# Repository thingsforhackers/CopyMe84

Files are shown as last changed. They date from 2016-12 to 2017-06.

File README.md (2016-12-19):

# CopyMe84

## Introduction

This repo contains the source code and KiCad project files for our CopyMe84 game kit.

The CopyMe84 game plays very similar to the classic "Simon Says" electionic game.

A complete kit looks like this:

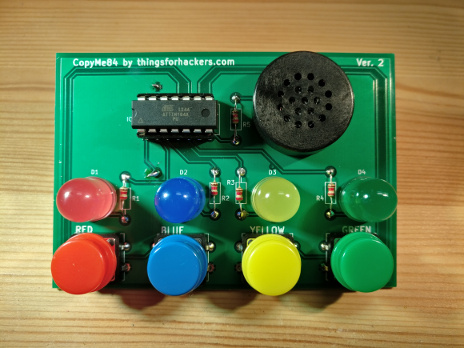
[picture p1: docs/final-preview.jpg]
Copy84A


Please visit [our store](https://thingsforhackers.com/store/) to purchase this kit.

When 1st powered on, i.e. when you insert the battery, it will play a nice('ish) title tune. After one loop of this tune, the game will enter power saving mode, press any button to wake it up.

To start the game, press any button during the title tune. The game play consitst of remember the sequence of LEDs, and pressing the corrosponding buttons in the correct order to repeat the sequence. Each sucessful loop the game will add another step to the sequence. To help, each LED flash is accompanied by a different beeper tone.

## HW Build Instructions

Full HW build instructions can be found on our [blog](https://thingsforhackers.com/post/build-instructions-copyme-84a/).

## SW Build Instructions

The kit contains a pre-programmed Ateml ATtiny84A microcontroller. However, as this is an open souce product you are albe to, infact we strongly encourge you to, modify, build and try out the code for yourself.

Inorder to build the code, you'll need a compiler that can target the Ateml AVR range of products. I would suggest starting [here](http://www.nongnu.org/avr-libc/user-manual/index.html).

If you're lucky enough to be on some sort of Linux box, I've written up [full instructions](https://thingsforhackers.com/post/installing-avr-libc/) on how to install the gcc tool chain for the AVRs.

Assuming you've got the gcc toolchain installed, the following shows you how to build the code:

If you haven't already, clone the github repo: `git clone git@github.com:thingsforhackers/CopyMe84.git`

Then simply `cd CopyMe84`, and type `make`.

If all went well, inside of the *obj* directory, you will find *copyme84.bin* & *copyme84.hex*, you should be able to use one of these files to program the ATtiny84A.

We use the *Mini Pro TL866CS programmer* to program pretty much all our products. You can pick one up from our [eBay store](http://www.ebay.co.uk/usr/thingsforhackers).

Which ever method you use to program, please ensure the *fuse* bits of the ATtiny84A are programmed as follows:

Byte | Value
-----|------
Low | 0x62
High | 0x5F
Ext | 0xFF

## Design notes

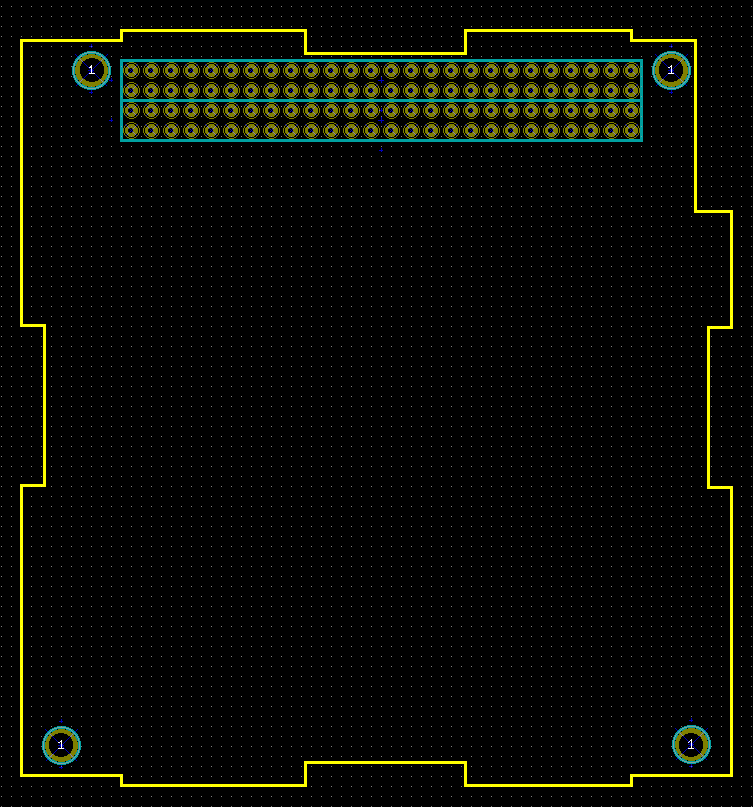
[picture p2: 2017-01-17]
hardware/pcb/etc/KiCad-Libraries/Templates/CubeSatKit_StackBoard/meta/Board.png

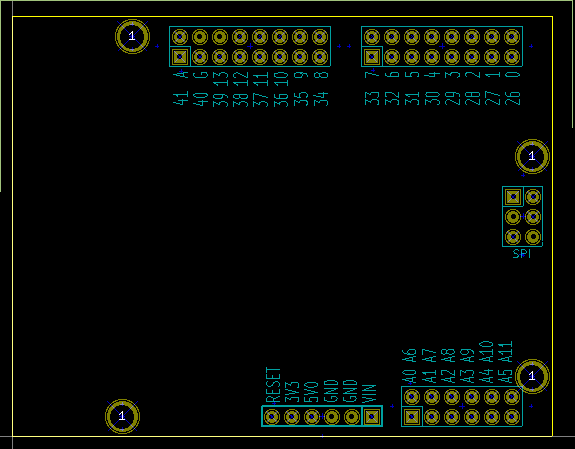
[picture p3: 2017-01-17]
hardware/pcb/etc/KiCad-Libraries/Templates/Chipkit_Shield_uC/meta/board.png

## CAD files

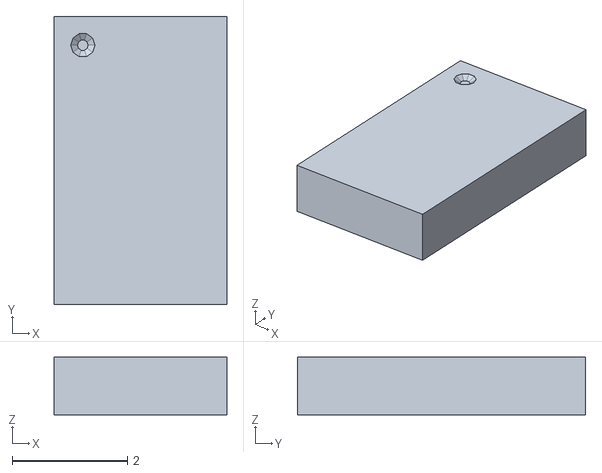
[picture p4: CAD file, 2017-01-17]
hardware/pcb/etc/KiCad-Libraries/3D/SourceFiles/ADXL345/ADXL345-Wings.stl
3.00 x 5.00 x 1.00

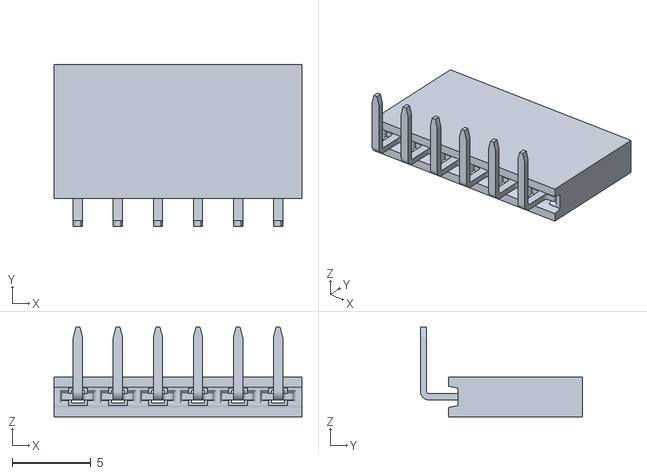
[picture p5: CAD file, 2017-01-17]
hardware/pcb/etc/KiCad-Libraries/3D/SourceFiles/Connectors/CONN_1x6/CONN_1x6_Female.stl
15.7 x 10.3 x 5.69

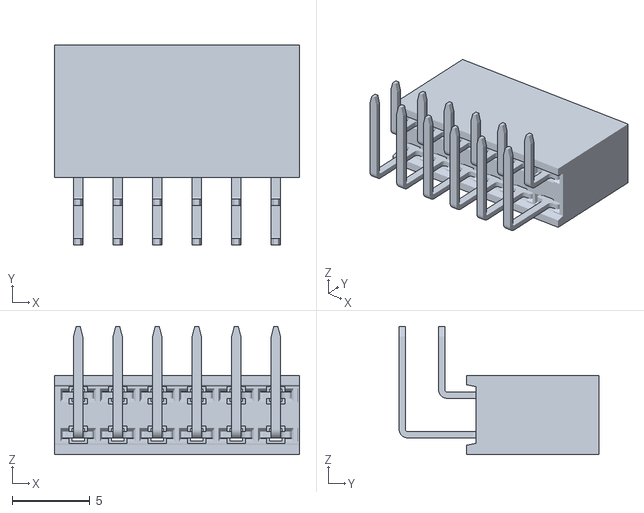
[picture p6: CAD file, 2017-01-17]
hardware/pcb/etc/KiCad-Libraries/3D/SourceFiles/Connectors/CONN_2x6/CONN_2x6_Female.stl
15.7 x 12.8 x 8.23

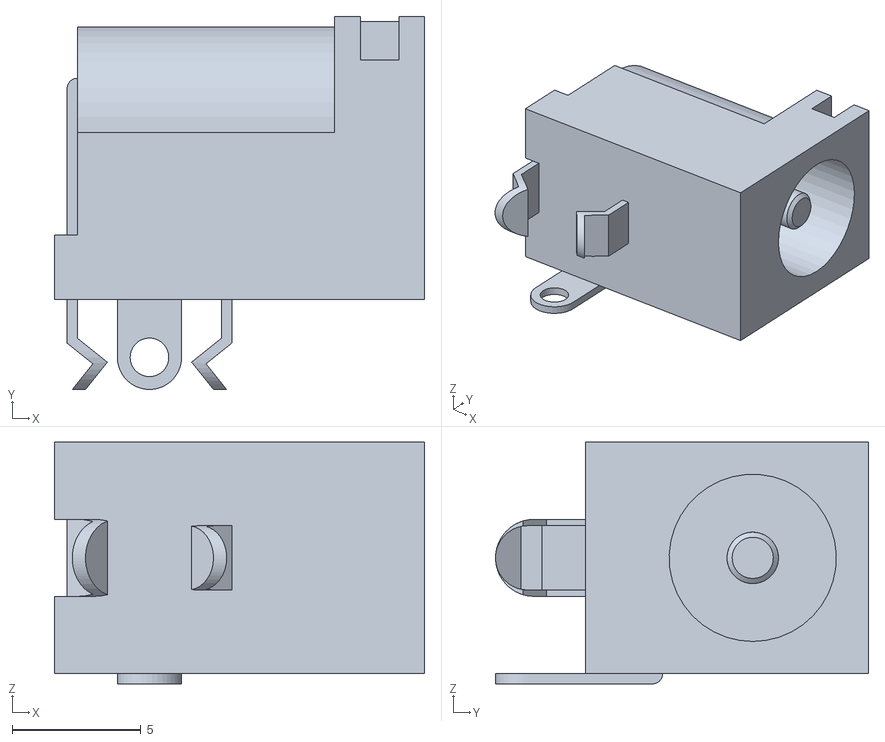
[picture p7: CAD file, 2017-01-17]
hardware/pcb/etc/KiCad-Libraries/3D/SourceFiles/Connectors/DC_2.1mm_CUI-PJ-202A/DC_2.1mm_CUI-PJ-202A.stl
14.4 x 14.5 x 9.40

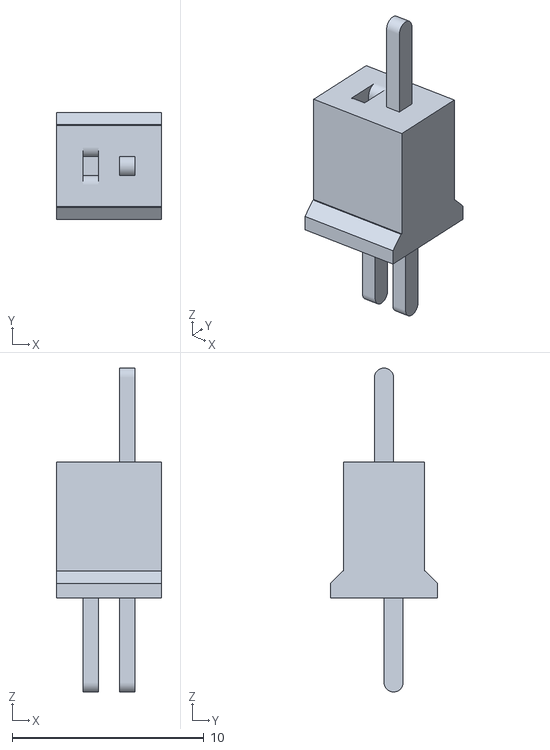
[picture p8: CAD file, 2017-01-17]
hardware/pcb/etc/KiCad-Libraries/3D/SourceFiles/Connectors/Deans/DeansMicro-Wings.stl
5.50 x 5.60 x 16.9

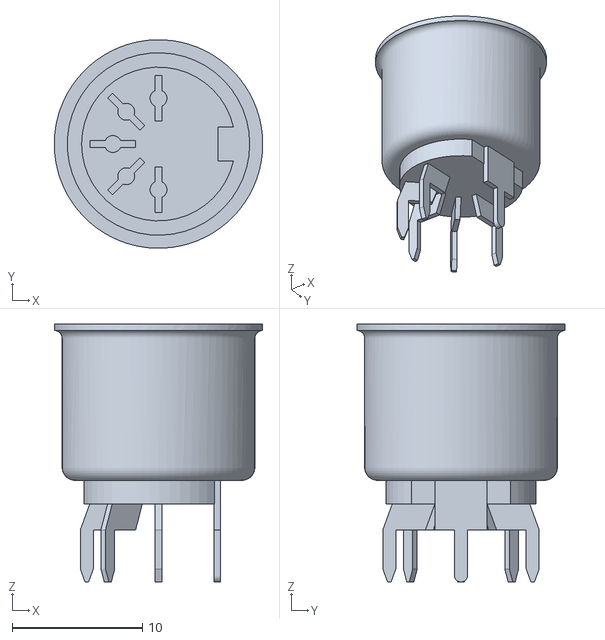
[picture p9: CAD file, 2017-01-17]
hardware/pcb/etc/KiCad-Libraries/3D/SourceFiles/Connectors/DIN_CUI_SD-50BV/SD-50BV.stl
16.0 x 16.0 x 19.8

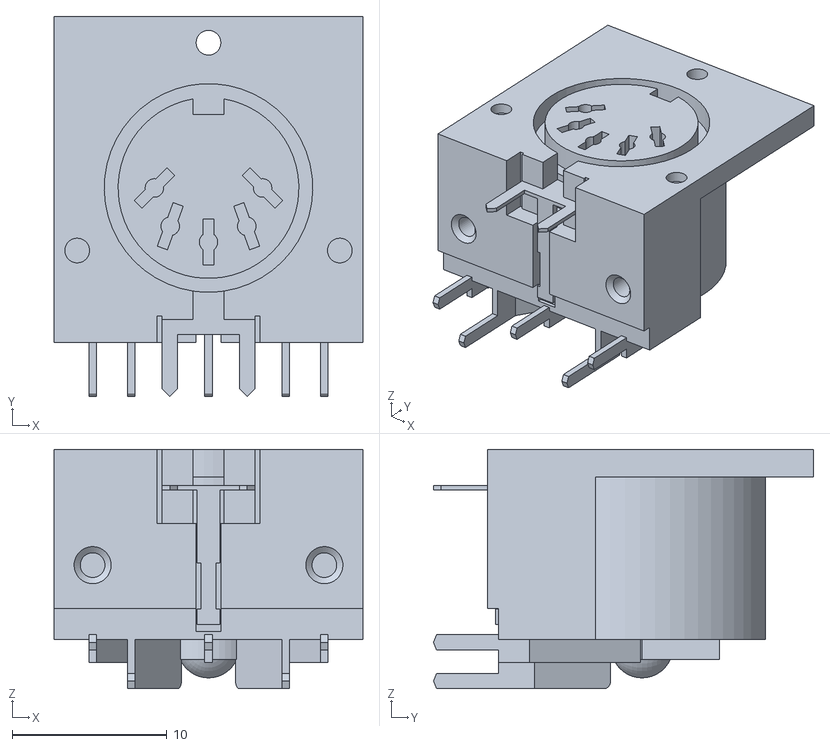
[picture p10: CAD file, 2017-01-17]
hardware/pcb/etc/KiCad-Libraries/3D/SourceFiles/Connectors/DIN_CUI_SDS-50J/SDS-50J.stl
20.0 x 24.6 x 15.5

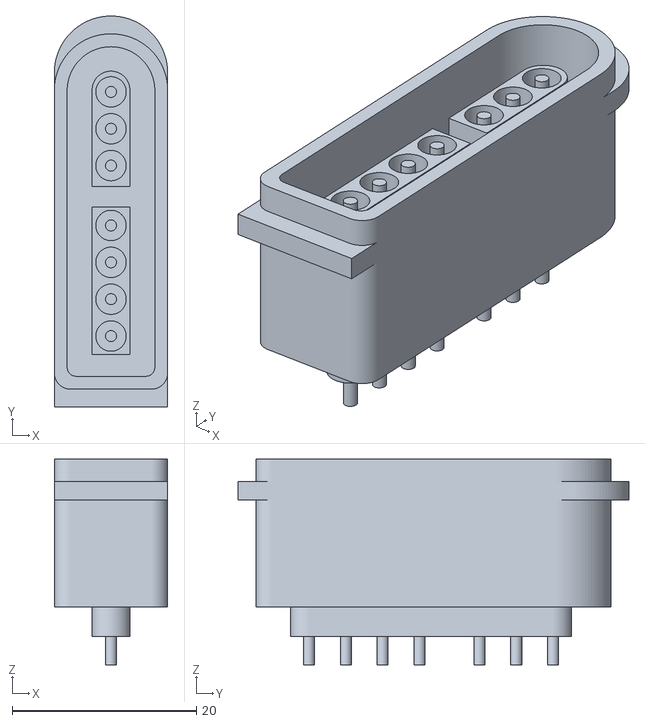
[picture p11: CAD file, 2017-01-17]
hardware/pcb/etc/KiCad-Libraries/3D/SourceFiles/Connectors/Gaming_SNES/Gaming_SNES-wings.stl
12.3 x 42.4 x 22.3

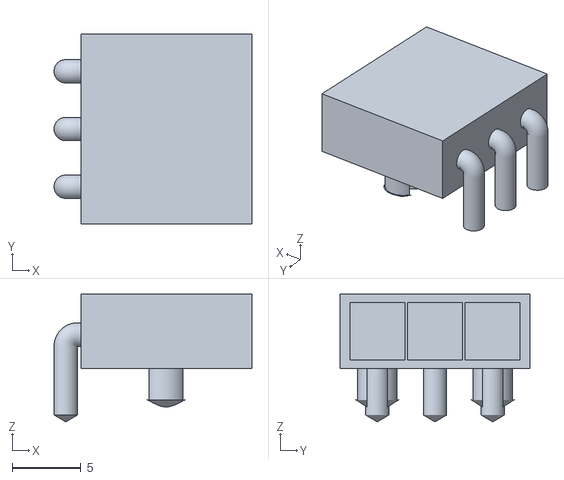
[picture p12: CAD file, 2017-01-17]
hardware/pcb/etc/KiCad-Libraries/3D/SourceFiles/Connectors/MOLEX_MINI-FIT-JR_3_PTH_RT_PEG/MOLEX_MINI-FIT-JR_3_PTH_RT_PEG-scad.stl
14.4 x 13.8 x 9.30

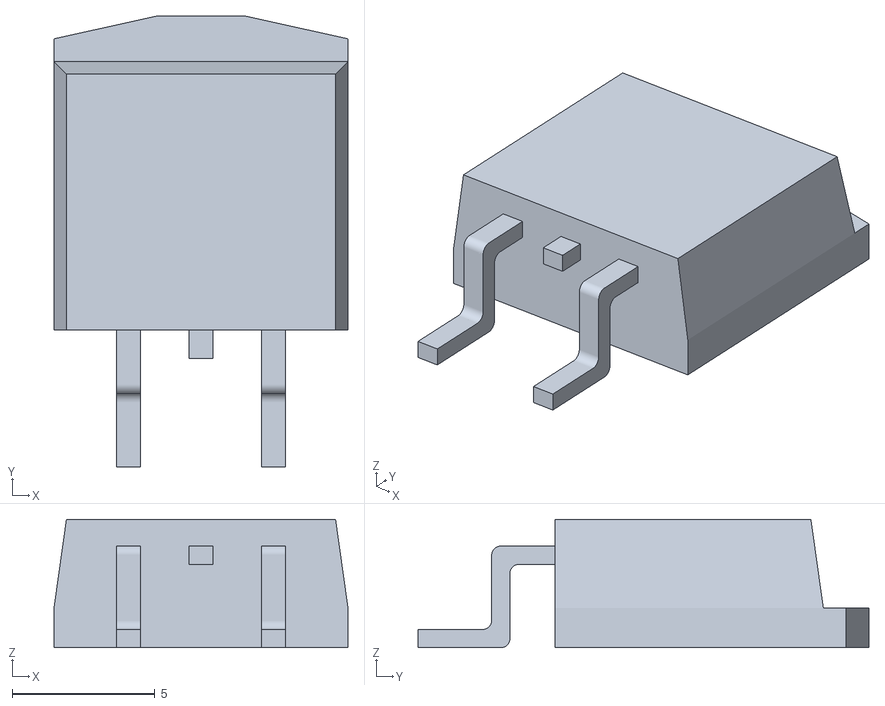
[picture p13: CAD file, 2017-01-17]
hardware/pcb/etc/KiCad-Libraries/3D/SourceFiles/D2PACK/D2PACK-SCAD.stl
10.3 x 15.8 x 4.50

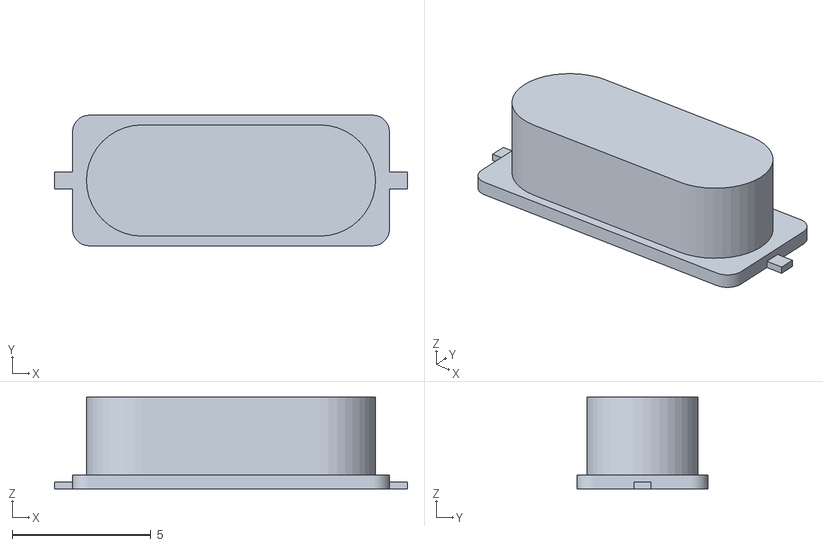
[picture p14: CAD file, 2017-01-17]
hardware/pcb/etc/KiCad-Libraries/3D/SourceFiles/HC-49-SMT/HC-49-SMT-scad.stl
12.7 x 4.70 x 3.30

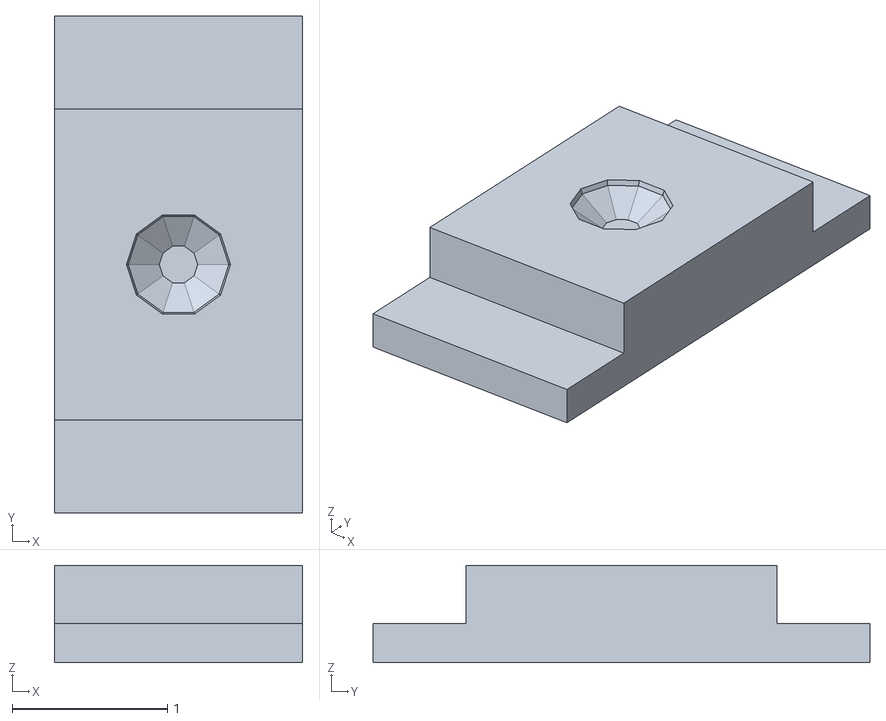
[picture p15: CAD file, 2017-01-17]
hardware/pcb/etc/KiCad-Libraries/3D/SourceFiles/LEDs/LED-1206-Wings.stl
1.60 x 3.20 x 0.625

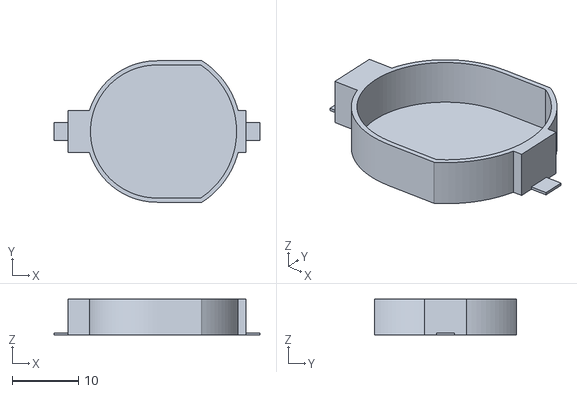
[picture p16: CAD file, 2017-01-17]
hardware/pcb/etc/KiCad-Libraries/3D/SourceFiles/MPD_CR2032/MPD_CR2032-SCAD.stl
31.1 x 21.4 x 5.38

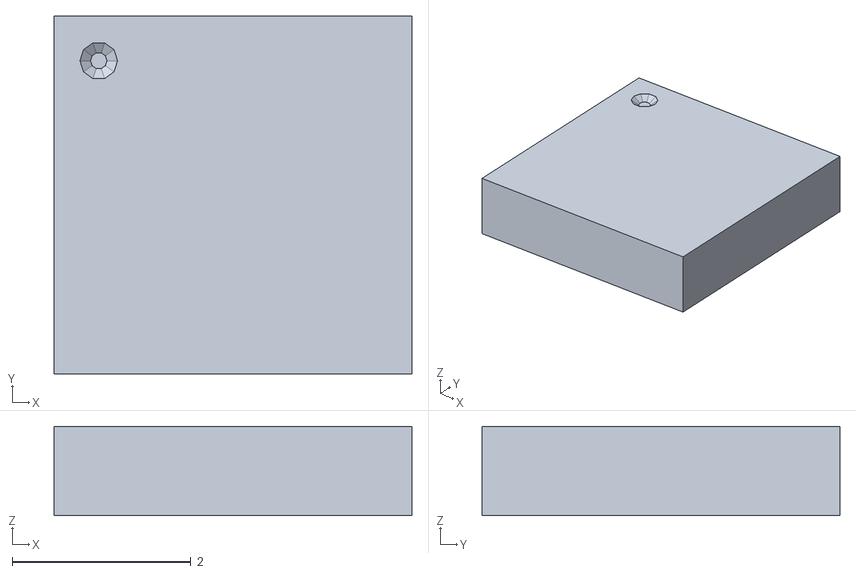
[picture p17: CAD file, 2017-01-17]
hardware/pcb/etc/KiCad-Libraries/3D/SourceFiles/MPU9150/MPU9150-Wings.stl
4.00 x 4.00 x 1.00

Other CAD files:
hardware/pcb/etc/KiCad-Libraries/3D/SourceFiles/SD_Objects/SD-Amp-microSlot-Wings.stl
hardware/pcb/etc/KiCad-Libraries/3D/SourceFiles/SMD_Passives/SMD-0805-scad.stl
hardware/pcb/etc/KiCad-Libraries/3D/SourceFiles/SOIC/SOIC_08_4.0mm_5.0mm_1.27mm-wings.stl
hardware/pcb/etc/KiCad-Libraries/3D/SourceFiles/SolarCells/Spectrolab_TASC1-SCAD.stl
hardware/pcb/etc/KiCad-Libraries/3D/SourceFiles/ADXL345/ADXL345.scad
hardware/pcb/etc/KiCad-Libraries/3D/SourceFiles/D2PACK/D2PACK.scad
hardware/pcb/etc/KiCad-Libraries/3D/SourceFiles/HC-49-SMT/HC-49-SMT.scad
hardware/pcb/etc/KiCad-Libraries/3D/SourceFiles/LEDs/LED-1206.scad
hardware/pcb/etc/KiCad-Libraries/3D/SourceFiles/ADXL345/ADXL345-SCAD.stl
hardware/pcb/etc/KiCad-Libraries/3D/SourceFiles/Connectors/CONN_1x6/CONN_1x6_Male.stl
hardware/pcb/etc/KiCad-Libraries/3D/SourceFiles/Connectors/CONN_2x6/CONN_2x6_Male.stl
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

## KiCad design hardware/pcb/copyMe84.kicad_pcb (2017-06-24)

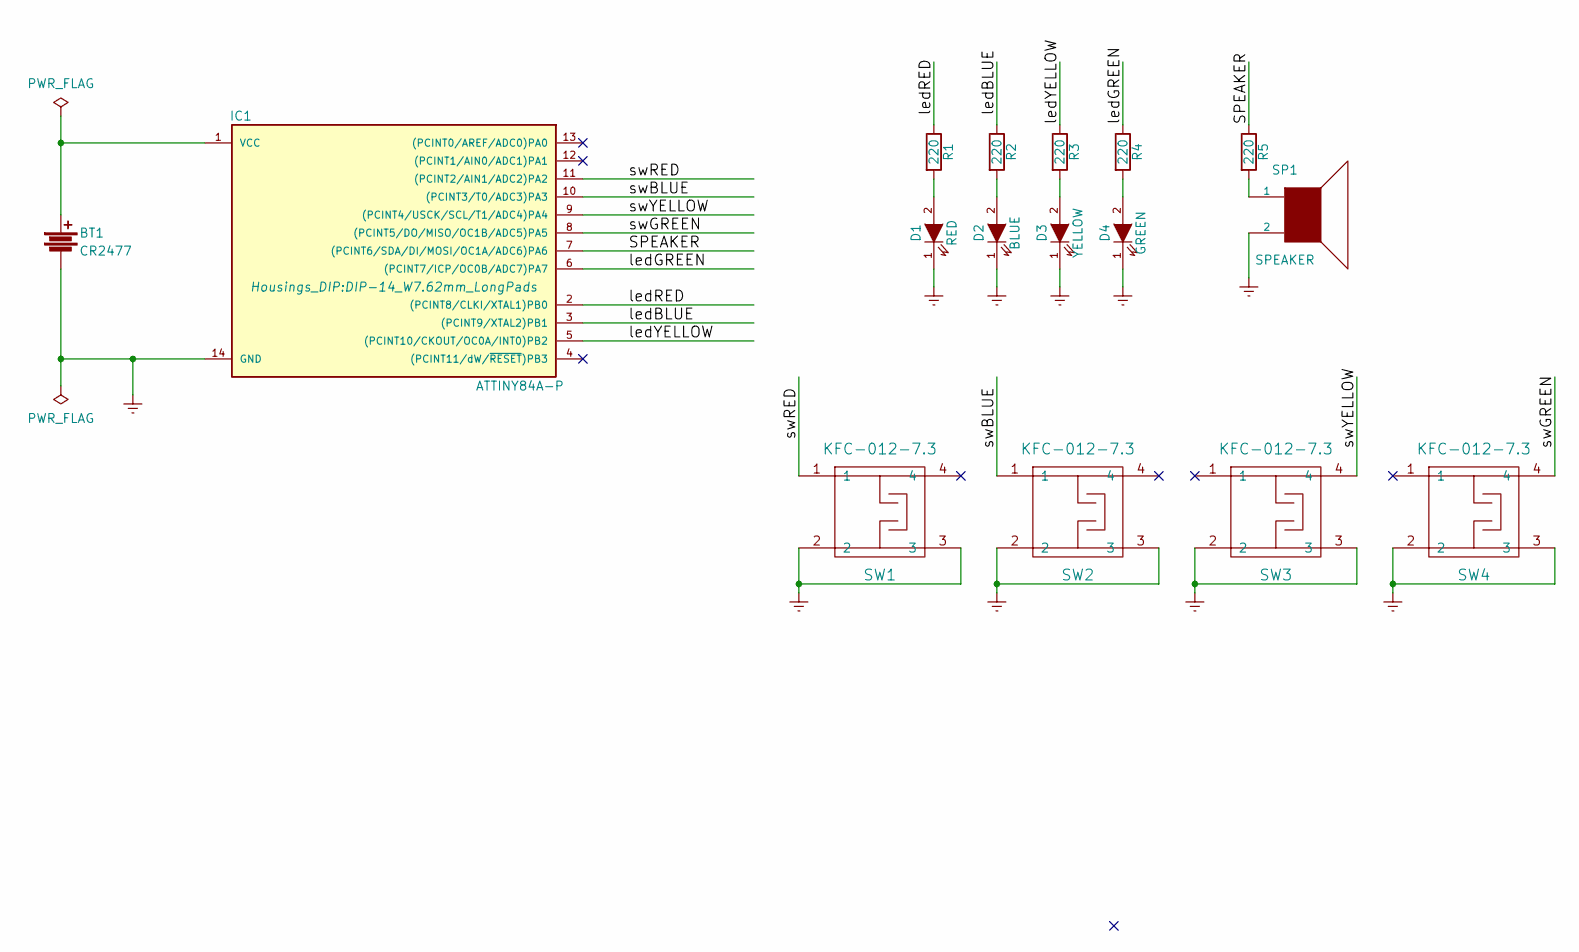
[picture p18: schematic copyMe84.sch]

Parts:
BT1: CR2477
D1: RED; LED-10MM
D2: BLUE; LED-10MM
D3: YELLOW; LED-10MM
D4: GREEN; LED-10MM
IC1: ATTINY84A-P; DIP-14_W7.62mm_LongPads
R1, R2, R3, R4, R5: 220; Resistor_Horizontal_RM10mm
SP1: SPEAKER; Speaker - MCABS-201-RC
SW1, SW2, SW3, SW4: KFC-012-7.3

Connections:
/SPEAKER: IC1.7 ((PCINT6/SDA/DI/MOSI/OC1A/ADC6)PA6), R5.1
/ledBLUE: IC1.3 ((PCINT9/XTAL2)PB1), R2.1
/ledGREEN: IC1.6 ((PCINT7/ICP/OC0B/ADC7)PA7), R4.1
/ledRED: IC1.2 ((PCINT8/CLKI/XTAL1)PB0), R1.1
/ledYELLOW: IC1.5 ((PCINT10/CKOUT/OC0A/INT0)PB2), R3.1
/swBLUE: IC1.10 ((PCINT3/T0/ADC3)PA3), SW2.1
/swGREEN: IC1.8 ((PCINT5/DO/MISO/OC1B/ADC5)PA5), SW4.4
/swRED: IC1.11 ((PCINT2/AIN1/ADC2)PA2), SW1.1
/swYELLOW: IC1.9 ((PCINT4/USCK/SCL/T1/ADC4)PA4), SW3.4
Earth: BT1.2, D1.1 (K), D2.1 (K), D3.1 (K), D4.1 (K), IC1.14 (GND), SP1.2, SW1.2, SW1.3, SW2.2, SW2.3, SW3.2, SW3.3, SW4.2, SW4.3
unnamed: BT1.1, IC1.1 (VCC)
unnamed: D1.2 (A), R1.2
unnamed: D2.2 (A), R2.2
unnamed: D3.2 (A), R3.2
unnamed: D4.2 (A), R4.2
unnamed: R5.2, SP1.1

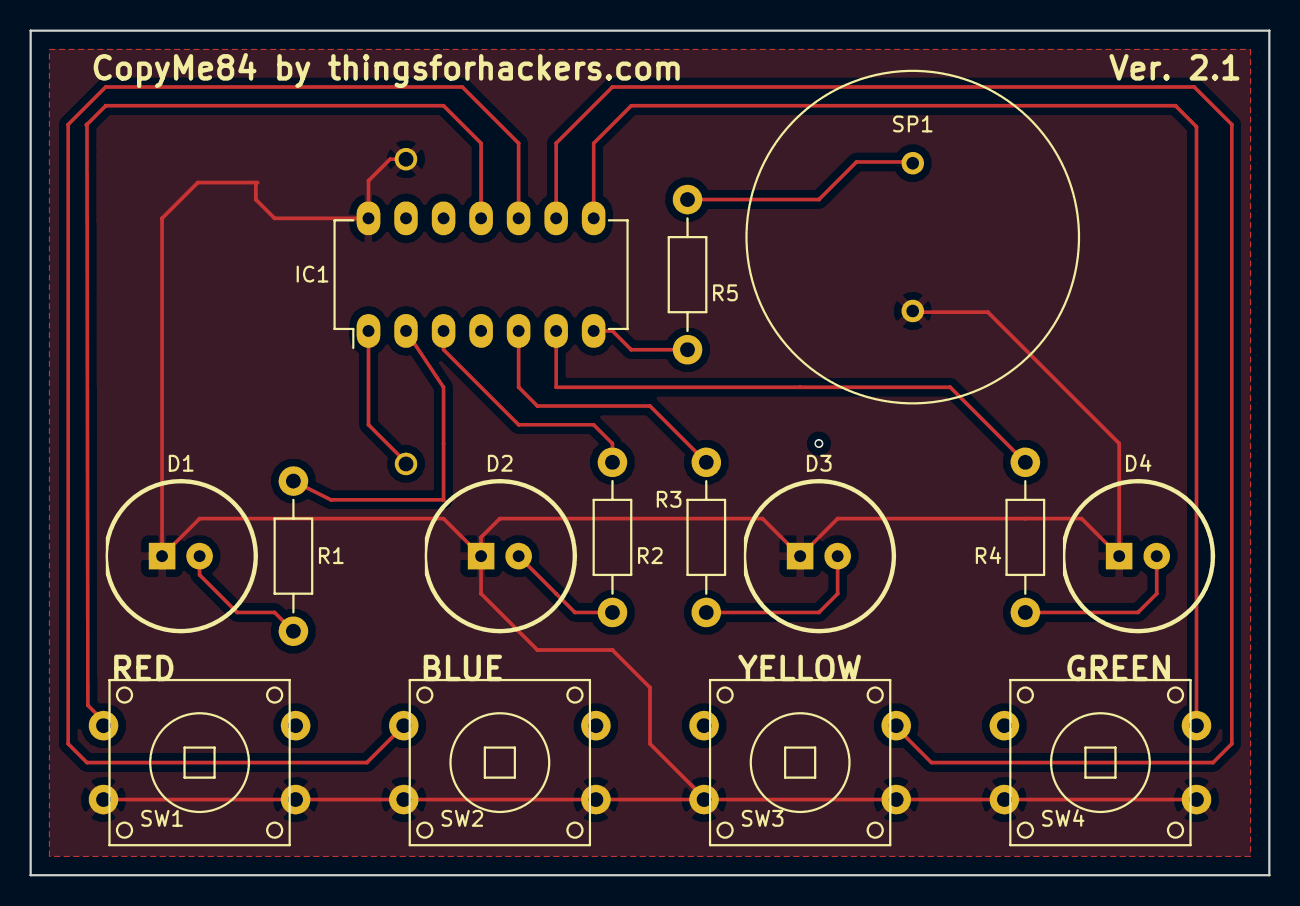
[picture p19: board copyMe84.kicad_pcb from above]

Board: 2 copper layers, 83.8 x 57.1 mm, 16 parts (1 on the bottom side), 16 nets.

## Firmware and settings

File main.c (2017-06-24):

/*
 * CopyMe84A
 *
 * Pin assignments
 *
 * Colour		LED			Switch   PCINT
 * ======   ======  =======  =====
 * Red			PB0(2)	PA2(11)  PCINT2
 * Blue			PB1(3)	PA3(10)  PCINT3
 * Yellow		PB2(5)	PA4(9)   PCINT4
 * Green		PA7(6)	PA5(8)   PCINT5
 *
 * 	Speaker: PA6(7)
 */
#include <avr/io.h>
#include <avr/interrupt.h>
#include <avr/sleep.h>
#include <util/atomic.h>
#include <stdlib.h>
#include <avr/pgmspace.h> // needed for PROGMEM
#include <util/delay.h>
#include <avr/wdt.h>
#include "button.h"
#include "state.h"
#include "tune.h"
#include "notes.h"
#include "tmr.h"

static const uint8_t RED_LED = PB0;
static const uint8_t BLUE_LED = PB1;
static const uint8_t YELLOW_LED = PB2;
static const uint8_t GREEN_LED = PA7;

#define RED_SWITCH PA2
#define BLUE_SWITCH PA3
#define YELLOW_SWITCH PA4
#define GREEN_SWITCH PA5

//Blue
#define NOTE_G4 ((uint16_t)392)
//Yellow
#define NOTE_C4 ((uint16_t)277)
//Red
#define NOTE_A4 ((uint16_t)440)
//Green
#define NOTE_G5 ((uint16_t)784)

static const uint8_t SPEAKER = PA6;
#define MAX_LEVEL 64
static uint8_t sequence[MAX_LEVEL];



//Snap of ticksSincePOR at time of wakeup
static uint8_t currentLevel;
static uint8_t currentStep;

#define MAX_DURATION ((uint32_t)398)
#define STEP_DURATION ((uint32_t)400)
#define REPEAT_STEP_TO 5000

uint16_t noteIdx;
uint32_t noteLen;
uint32_t noteDly;

static struct StateM mainSM;

volatile uint32_t toneStopTime;

volatile uint32_t toggle_count;

uint16_t noteArray3[] = {
    C4, E4, G4, C5, E5, G4, C5, E5
};


volatile uint16_t led22;

ISR(TIM1_COMPA_vect)
{
  if(millis() >= toneStopTime)
  {
    TCCR1B = 0; //Stop Timer1
  }
}

void enterDeepSleep(void)
{
  PCMSK0 |= _BV(PCINT2) | _BV(PCINT3) | _BV(PCINT4) | _BV(PCINT5);
  GIMSK |= _BV(PCIE0);
  set_sleep_mode(SLEEP_MODE_PWR_DOWN);
  sleep_enable();
  sei();
  sleep_cpu();
  cli();
  GIMSK &= ~_BV(PCIE0);
  wdt_enable(WDTO_15MS);
  while(1);
}
EMPTY_INTERRUPT(PCINT0_vect);

uint8_t isNoteFinished(void)
{
  return TCCR1B == 0;
}

// 1MHz clk, preScale 8, /2 for toggle
#define TMR1_FREQ ((uint16_t)( (F_CPU / 8) / 2 ))
// note in Hz
// duration in ms
void playNote(uint16_t note, uint32_t duration)
{
  uint16_t cmpValue = TMR1_FREQ / note;

  uint8_t valueHigh = (cmpValue >> 8) & 0xFF;
  uint8_t valueLow = cmpValue & 0xFF;

  cli();
  TIFR1 = _BV(OCF1A);
  toneStopTime = millis() + duration;
  toggle_count = duration;
  OCR1AH = valueHigh;
  OCR1AL = valueLow;
  TCCR1B = _BV(WGM12) | _BV(CS11);
  sei();
}

void stopNote()
{
  cli();
  TCCR1B = 0;
  TIFR1 = _BV(OCF1A);
  sei();
}

typedef enum
{
    GAME_STATE_POR,                           //0 - Power on reset

    GAME_STATE_PRE_GAME,                      //1
    GAME_STATE_PLAY_SEQUENCE_INIT,            //2
    GAME_STATE_PLAY_SEQUENCE_INDICATE_STEP,   //3
    GAME_STATE_PLAY_SEQUENCE_INDICATE_DELAY,  //4

    GAME_STATE_CHECK_SEQUENCE_PAUSE,          //5 - Delay before start
    GAME_STATE_CHECK_SEQUENCE,                //6 - Player plays back sequence
    GAME_STATE_CHECK_SEQUENCE_INDICATE,       //7
    GAME_STATE_GAME_OVER,                      //8

    GAME_STATE_TITLE_TUNE_START,
    GAME_STATE_TITLE_TUNE_PLAY_NOTE,
    GAME_STATE_TITLE_TUNE_HOLD_NOTE


} GameState;

typedef enum INDICATION_ID
{
  INDICATE_RED,
  INDICATE_BLUE,
  INDICATE_YELLOW,
  INDICATE_GREEN,

  INDICATE_CNT

} INDICATION_ID;
static const uint8_t NO_KEY = INDICATE_CNT;

typedef enum
{
  RED_BUTTON_IDX,
  BLUE_BUTTON_IDX,
  YELLOW_BUTTON_IDX,
  GREEN_BUTTON_IDX,

  BUTTON_CNT

} ButtonIdx;
static ButtonCtx buttons[BUTTON_CNT] =
{
    //RED_BUTTON_IDX
    {&PINA, RED_SWITCH, BUTTON_UP, 0},
    //BLUE_BUTTON_IDX,
    {&PINA, BLUE_SWITCH, BUTTON_UP, 0},
    //YELLOW_BUTTON_IDX,
    {&PINA, YELLOW_SWITCH, BUTTON_UP, 0},
    //GREEN_BUTTON_IDX,
    {&PINA, GREEN_SWITCH, BUTTON_UP, 0},
};

static void indicateFail()
{
  playNote(150, 3000);
  PORTB = _BV(RED_LED) | _BV(BLUE_LED) | _BV(YELLOW_LED);
  PORTA |= _BV(GREEN_LED);
}

static void stepEnd()
{
  stopNote();
  PORTB = 0;
  PORTA = (uint8_t)~(_BV(SPEAKER) | _BV(GREEN_LED)); //Unused pull high as well
}

static void doIndicateStep(uint8_t step)
{

  switch(sequence[step])
  {
    case INDICATE_RED:
    {
      playNote(NOTE_A4, MAX_DURATION);
      PORTB |= _BV(RED_LED);
      break;
    }

    case INDICATE_BLUE:
    {
      playNote(NOTE_G4, MAX_DURATION);
      PORTB |= _BV(BLUE_LED);
      break;
    }

    case INDICATE_YELLOW:
    {
      playNote(NOTE_C4, MAX_DURATION);
      PORTB |= _BV(YELLOW_LED);
      break;
    }

    case INDICATE_GREEN:
    {
      playNote(NOTE_G5, MAX_DURATION);
      PORTA |= _BV(GREEN_LED);
      break;
    }
  }
}

static void generateSequence(void)
{
  for(int idx = 0; idx < MAX_LEVEL; idx++)
  {
    sequence[idx] = (uint8_t)(rand() % INDICATE_CNT);
  }
}

static uint8_t getInput()
{
  uint8_t pressed;

  if(buttons[RED_BUTTON_IDX].state == BUTTON_DOWN)
  {
      pressed = INDICATE_RED;
  }
  else if(buttons[BLUE_BUTTON_IDX].state == BUTTON_DOWN)
  {
      pressed = INDICATE_BLUE;
  }
  else if(buttons[YELLOW_BUTTON_IDX].state == BUTTON_DOWN)
  {
      pressed = INDICATE_YELLOW;
  }
  else if(buttons[GREEN_BUTTON_IDX].state == BUTTON_DOWN)
  {
      pressed = INDICATE_GREEN;
  }
  else
  {
    pressed = NO_KEY;
  }

  return pressed;
}

static uint8_t mainStateFunc(struct StateM* sm)
{
  uint8_t retValue = 0;

  switch(sm->current)
  {
    case GAME_STATE_POR:
    {
      if(isStateEntered(sm))
      {
        currentLevel = 1;
      }
      else if(getStateDuration(sm) > 2000)
      {
        //sm->next = GAME_STATE_PRE_GAME;
        sm->next = GAME_STATE_TITLE_TUNE_START;
      }
      break;
    }

    case GAME_STATE_PRE_GAME:
    {
      static uint8_t ledsA = 0;
      static uint8_t ledsB = 0;
      if(getInput() != NO_KEY)
      {
        srand(millis());
        generateSequence();
        sm->next = GAME_STATE_PLAY_SEQUENCE_INIT;
        ledsA = 0;
        ledsB = 0;
      }
      else if(getStateDuration(sm) > 500)
      {
        sm->enterTime = millis();
        ledsA = ledsA ? 0 : _BV(RED_LED) | _BV(BLUE_LED) | _BV(YELLOW_LED);
        ledsB = ledsB ? 0 : _BV(GREEN_LED);
      }
      PORTA = ledsA;
      PORTB = ledsB;
      break;
    }

    case GAME_STATE_PLAY_SEQUENCE_INIT:
    {
      if(getStateDuration(sm) > 2000)
      {
        currentStep = 0;
        sm->next = GAME_STATE_PLAY_SEQUENCE_INDICATE_STEP;
      }
      break;
    }

    case GAME_STATE_PLAY_SEQUENCE_INDICATE_STEP:
    {
      doIndicateStep(currentStep);
      sm->next = GAME_STATE_PLAY_SEQUENCE_INDICATE_DELAY;
      break;
    }

    case GAME_STATE_PLAY_SEQUENCE_INDICATE_DELAY:
    {
      if(getStateDuration(sm) > STEP_DURATION)
      {
        stepEnd();
        currentStep++;
        if(currentStep >= currentLevel)
        {
          //All done, now handle player repeating this level
          currentStep = 0;
          sm->next = GAME_STATE_CHECK_SEQUENCE;
        }
        else
        {
          //Play next step in this sequence
          sm->next = GAME_STATE_PLAY_SEQUENCE_INDICATE_STEP;
        }
      }
      break;
    }

    case GAME_STATE_CHECK_SEQUENCE:
    {
      if( getStateDuration(sm) > REPEAT_STEP_TO )
      {
        sm->next = GAME_STATE_GAME_OVER;
      }
      else
      {
        uint8_t playerKey = getInput();

        if(playerKey != NO_KEY)
        {
          if(sequence[currentStep] == playerKey)
          {
            doIndicateStep(currentStep);
            sm->next = GAME_STATE_CHECK_SEQUENCE_INDICATE;
          }
          else
          {
            sm->next = GAME_STATE_GAME_OVER;
          }
        }
      }
      break;
    }

    case GAME_STATE_CHECK_SEQUENCE_INDICATE:
    {
      if( getStateDuration(sm) > STEP_DURATION )
      {
        stepEnd();
        currentStep++;
        if(currentStep >= currentLevel)
        {
          //All done, now handle player repeating this level
          currentLevel++;
          if(currentLevel > MAX_LEVEL )
          {
            sm->next = GAME_STATE_GAME_OVER;
          }
          else
          {
            sm->next = GAME_STATE_PLAY_SEQUENCE_INIT;
          }
        }
        else
        {
          //Play next step in this sequence
          sm->next = GAME_STATE_CHECK_SEQUENCE;
        }
      }
      break;
    }

    case GAME_STATE_GAME_OVER:
    {
      if(isStateEntered(sm))
      {
        indicateFail();
      }
      else if(getStateDuration(sm) > 4000)
      {
        stepEnd();
        sm->next = GAME_STATE_POR;
      }
      break;
    }

    case GAME_STATE_TITLE_TUNE_START:
    {
      noteIdx = 0;
      noteLen = 150;
      noteDly = 190;
      sm->next = GAME_STATE_TITLE_TUNE_PLAY_NOTE;
      break;
    }

    case GAME_STATE_TITLE_TUNE_PLAY_NOTE:
    {
      if(getInput() == NO_KEY)
      {
        uint16_t noteFreq = pgm_read_word(&(noteArray[noteIdx]));
        playNote(noteFreq, noteFreq * noteLen / 500);
        sm->next = GAME_STATE_TITLE_TUNE_HOLD_NOTE;
      }
      else
      {
        stopNote();
        sm->next = GAME_STATE_PRE_GAME;
      }
      break;
    }

    case GAME_STATE_TITLE_TUNE_HOLD_NOTE:
    {
      if(isNoteFinished() && getStateDuration(sm) > noteDly)
      {
        if((noteIdx > 512) && (noteIdx < 540)) // slow down (rit.) at end.
        {
          noteLen += 3;
          noteDly += 5;
        }
        noteIdx++;
        if (noteIdx == TUNE_LENGTH)
        {
          sm->next = GAME_STATE_POR;
          enterDeepSleep();
        }
        else
        {
          sm->next = GAME_STATE_TITLE_TUNE_PLAY_NOTE;
        }
      }

      break;
    }

    case STATE_INVALID:
    default:
    {
      sm->next = GAME_STATE_POR;
      break;
    }
  }

  return retValue;
}

int main (void)
{
  MCUSR = 0;
  wdt_disable();

  //Setup Pins
  DDRA = _BV(SPEAKER) | _BV(GREEN_LED); //Unused as inputs
  PORTA = (uint8_t)~(_BV(SPEAKER) | _BV(GREEN_LED)); //Unused pull high as well
  DDRB = _BV(RED_LED) | _BV(BLUE_LED) | _BV(YELLOW_LED);
  PORTB = 0;

  startTmr();

  ACSR = _BV(ACD); //Don't need ADC

  TCCR1B = 0;
  TIFR1 = _BV(OCF1A);
  TCCR1A = _BV(COM1A0);
  TCCR1B = _BV(WGM12) | _BV(CS11);
  TIMSK1 |= _BV(OCIE1A);

  sei();

  initButtons(buttons, BUTTON_CNT);
  initStateM(&mainSM, mainStateFunc);

  while(1)
  {
    sleep_mode();
    updateButtons(buttons, BUTTON_CNT);
    runStateM(&mainSM);
  }

  return 0;
}

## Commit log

2016-06-11 Initial working version.
    [copyme84.kicad_pcb, copyme84.sch]
2016-06-25 Removed old hw
    [copyme84.kicad_pcb, copyme84.sch]
2016-06-25 Updated with latest HW
    [copyMe84-B.Cu.gbr, copyMe84-B.Mask.gbr, copyMe84-B.SilkS.gbr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]
2017-01-17 Updated missing libs
    [ADXL345-SCAD.stl, ADXL345-Wings.stl, ADXL345.scad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]
2017-06-24 Fixed up code for Ver 2.1 board
    [main.c]
2017-12-17 update kicad project
